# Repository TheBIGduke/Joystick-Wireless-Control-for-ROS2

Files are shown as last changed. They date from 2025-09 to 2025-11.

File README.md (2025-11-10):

# ESP32 Joystick Controller for ROS2






Control your ROS2 robot wirelessly using an ESP32 and analog joystick. Features real-time Socket.IO communication, variable speed control, and RGB LED status indicators.

## Features

- **Real-time wireless control** with analog joystick
- **Variable speed control** (half/full speed based on joystick position)
- **Seamless ROS2 integration** via delivery_bridge
- **RGB LED status indicators** for system feedback
- **Automatic reconnection** with robust error handling
- **Low-latency Socket.IO** communication

## Table of Contents

- [Hardware Requirements](#hardware-requirements)
- [Software Requirements](#software-requirements)
- [Installation](#installation)
- [Configuration](#configuration)
- [Usage](#usage)
- [LED Status Reference](#led-status-reference)
- [Troubleshooting](#troubleshooting)
- [Project Structure](#project-structure)
- [API Reference](#api-reference)
- [Contributing](#contributing)

## Hardware Requirements

### Components
- ESP32 Development Board (DevKitC, NodeMCU-32S, or compatible)
- Analog Joystick Module (2-axis with VRX/VRY outputs)
- Common Anode RGB LED
- Pushbutton (Dead Man Switch)
- 3× 220Ω resistors (for RGB LED)
- Jumper wires
- USB cable (micro-USB or USB-C)

### Wiring Diagram

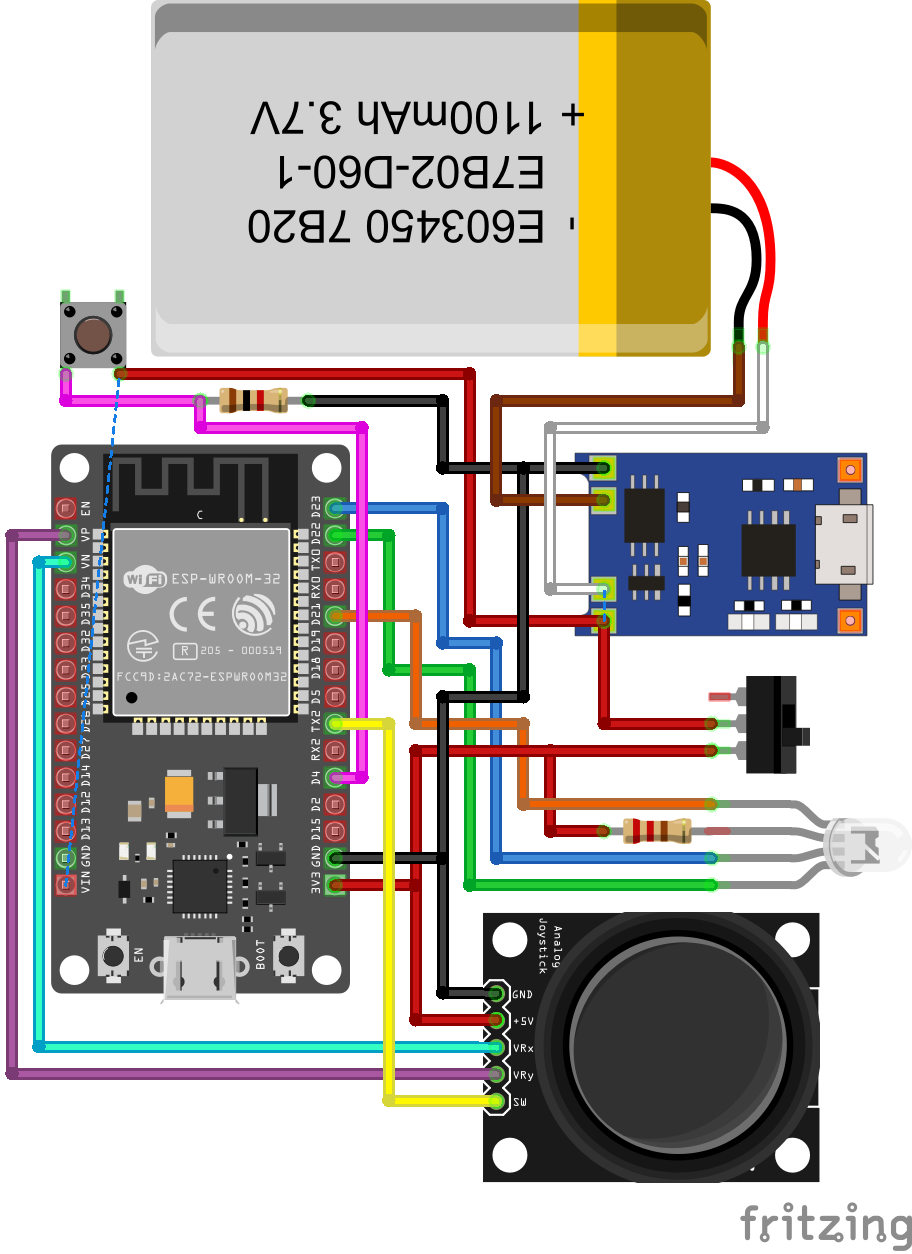
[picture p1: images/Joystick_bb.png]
ESP32 Wiring Diagram


#### Joystick Connections
```
Joystick → ESP32
VCC      → 3.3V
GND      → GND
VRX      → GPIO39 (ADC3)
VRY      → GPIO36 (ADC0)
```

#### Pushbutton (Dead Man Switch)
```
Pushbutton → ESP32
One side   → GPIO4
Other side → GND
```

#### RGB LED (Common Anode)
```
RGB LED        → ESP32
Red Cathode    → GPIO25 (+ 220Ω resistor)
Green Cathode  → GPIO26 (+ 220Ω resistor)
Blue Cathode   → GPIO27 (+ 220Ω resistor)
Common Anode   → 3.3V
```

## Software Requirements

- **Visual Studio Code** with PlatformIO IDE extension
- **ROS2** (Humble or newer)
- **Python 3.8+**
- **Git**

## Installation

### 1. Install Development Tools

#### Visual Studio Code + PlatformIO
1. Download and install [Visual Studio Code](https://code.visualstudio.com/)
2. Install PlatformIO IDE extension:
   - Open VS Code
   - Go to Extensions (`Ctrl+Shift+X`)
   - Search for "PlatformIO IDE"
   - Click "Install" and restart VS Code

### 2. Clone Repository

```bash
cd ~/colcon_ws/src
git clone https://github.com/TheBIGduke/Joystick-Wireless-Control-for-ROS2.git
cd Joystick-Wireless-Control-for-ROS2
```

### 3. Setup ROS2 Delivery Bridge

**Prerequisites:** ROS2 Humble or newer installed ([installation guide](https://docs.ros.org/en/humble/Installation.html))

```bash
# Install Python dependencies
cd delivery_bridge
pip install -r requirements.txt

# Build the ROS2 package
cd ~/colcon_ws
colcon build --packages-select delivery_bridge --symlink-install
source install/setup.bash

# Test the delivery bridge
ros2 run delivery_bridge server_node
```

**Expected output:**
```
[INFO] [server_node]: Starting node BaseNode ...
[INFO] [server_node]: Database created successfully.
INFO: Uvicorn running on http://0.0.0.0:9009
INFO: connection open
```

Verify at `http://localhost:9009/docs`

### 4. Setup ESP32 Project

```bash
cd ~/colcon_ws/src/Joystick-Wireless-Control-for-ROS2/Joystick_SocketIO_ESP32
code .
```

PlatformIO will automatically detect and initialize the project.

## Configuration

### Step 1: Find Server IP Address

Find the IP address of the computer running the delivery bridge:

**Linux:**
```bash
hostname -I
# or
ip addr show
```

### Step 2: Configure ESP32 Settings

Edit `Joystick_SocketIO_ESP32/src/main.cpp`:

```cpp
// ============ REQUIRED CONFIGURATION ============

// WiFi credentials
const char* ssid = "YOUR_WIFI_NAME";
const char* password = "YOUR_WIFI_PASSWORD";

// Socket.IO server (delivery bridge)
const char* socketio_host = "192.168.0.103";  // Replace with your server IP
const int socketio_port = 9009;

// ============ OPTIONAL TUNING ============

// Joystick calibration (adjust based on your joystick)
#define CENTER_X 1945
#define CENTER_Y 2005
#define DEADZONE 4

// Speed settings
const float LINEAR_SPEED_FULL = 0.4;   // m/s
const float LINEAR_SPEED_HALF = 0.2;   // m/s
const float ANGULAR_SPEED_FULL = 0.6;  // rad/s
const float ANGULAR_SPEED_HALF = 0.3;  // rad/s
const int SPEED_THRESHOLD = 250;       // Threshold for half vs full speed
```

### Step 3: Calibrate Joystick (Optional)

To get accurate center values:

1. Upload the default code to ESP32
2. Open Serial Monitor (9600 baud)
3. Observe joystick readings at rest position
4. Note the X and Y values (e.g., `x = 1945, y = 2005`)
5. Update `CENTER_X` and `CENTER_Y` in the code
6. Re-upload to ESP32

## Usage

### LED indicators (startup sequence)
Follow the LED colors during startup — do not move the joystick while calibration is in progress.

- 🟠 Orange (blinking) — Calibrating joystick. Do NOT move the joystick until the LED turns solid orange.
- 🟠 Orange (solid)  — Calibration complete; startup continues.
- 🔵 Blue (blinking) — Connecting to WiFi.
- 🔵 Blue (solid)    — WiFi connected.
- 🟡 Yellow (blinking) — Connecting to Socket.IO (delivery_bridge).
- 🟡 Yellow (solid)    — Socket.IO connected.
- 🟢 Green (solid)   — System ready. You may control the robot.

To move the robot: press and hold the deadman switch while operating the joystick.
To stop the robot: release the joystick to center OR (in emergencies) release the deadman switch immediately.

### 1. Start the Delivery Bridge

```bash
cd ~/colcon_ws
source /opt/ros/humble/setup.bash
source install/setup.bash
ros2 run delivery_bridge server_node
```

### 2. Upload Code to ESP32

**Using VS Code:**
1. Connect ESP32 via USB
2. Click PlatformIO icon in sidebar
3. Project Tasks → esp32doit-devkit-v1 → General → Upload

**Using CLI:**
```bash
cd Joystick_SocketIO_ESP32
pio run -t upload
```

### 3. Monitor Serial Output

```bash
pio device monitor -b 9600
```

**Expected output:**
```
Connecting to WiFi...
Connected to WiFi
IP address: 192.168.0.101
[IOc] Connected to url: /socket.io/?EIO=4
=== Joystick Wireless Control for ROS2 Started ===
Joystick - x = 0, y = 0
Movement: STOPPED | linear_x=0.00, angular_z=0.00
```

### 4. Verify ROS2 Communication

```bash
# Check cmd_vel topic
ros2 topic echo /cmd_vel
```

**Expected output when moving joystick:**
```
linear:
  x: 0.2
  y: 0.0
  z: 0.0
angular:
  x: 0.0
  y: 0.0
  z: -0.3
```

## LED Status Reference

| Color | Pattern | Status |
|---|---|---|
| 🔵 Blue | Fast blink | Connecting to WiFi |
| 🔵 Blue | Solid | WiFi connected |
| 🟡 Yellow | Fast blink | Connecting to Socket.IO |
| 🟡 Yellow | Solid | Socket.IO connected |
| 🟢 Green | Solid | System ready |
| 🟣 Magenta | Slow pulse | Dead man switch (no input) |
| 🟣 Magenta | Rapid pulse | Dead man switch (with input) |
| 🟠 Orange | Fast blink | Calibrating |
| 🔴 Red | Triple blink | Error |

## Troubleshooting

### WiFi Connection Issues

**Problem:** ESP32 won't connect to WiFi

**Solutions:**
- Verify WiFi credentials in `main.cpp`
- Ensure network is 2.4GHz (ESP32 doesn't support 5GHz)
- Check ESP32 is within router range
- Try a different WiFi network

### Socket.IO Connection Failed

**Problem:** WiFi connected but Socket.IO fails

**Solutions:**
- Verify delivery bridge is running: `ros2 run delivery_bridge server_node`
- Check server IP address in ESP32 code matches your computer
- Ensure both devices are on the same network
- Test server: `telnet YOUR_IP 9009`

### Joystick Not Responding

**Problem:** Robot doesn't move when joystick is moved

**Solutions:**
- **Check wiring:** VRX→GPIO39, VRY→GPIO36, VCC→3.3V, GND→GND
- **Verify power:** Joystick receives 3.3V
- **Calibrate:** Update `CENTER_X` and `CENTER_Y` values
- **Check serial:** Monitor joystick readings
- **Adjust deadzone:** If too sensitive, increase `DEADZONE` value

### Wrong Movement Direction

**Problem:** Robot moves in unexpected directions

**Solutions:**
- Swap VRX/VRY pin connections
- Or modify code to invert axes:
```cpp
// In readJoystick() function:
valueX = -analogRead(VRY_PIN);  // Add minus sign
```

### Robot Doesn't Move

**Problem:** ESP32 connected but robot unresponsive

**Solutions:**
- Check ROS2 topics: `ros2 topic list`
- Monitor cmd_vel: `ros2 topic echo /cmd_vel`
- Verify delivery bridge logs show received events
- Check robot is in correct operational mode

### Serial Monitor Shows Nothing

**Problem:** No output in serial monitor

**Solutions:**
- Verify baud rate is 9600
- Check USB cable connection
- Try different USB port
- Press ESP32 reset button
- Confirm correct COM port

## Project Structure

```
Joystick-Wireless-Control-for-ROS2/
├── Joystick_SocketIO_ESP32/
│   ├── src/
│   │   └── main.cpp              # ESP32 joystick controller
│   ├── platformio.ini            # PlatformIO configuration
│   └── .vscode/
├── delivery_bridge/
│   ├── delivery_bridge/
│   │   ├── base_node.py          # ROS2 base node
│   │   ├── server_node.py        # Socket.IO server
│   │   └── modules/              # ROS2 functionality
│   ├── package.xml
│   ├── setup.py
│   └── requirements.txt
└── README.md
```

## API Reference

### cmd_vel Message Format

ESP32 sends velocity commands to ROS2:

```json
[
  "cmd_vel",
  {
    "linear_x": 0.2,    // Forward/backward (m/s)
    "angular_z": 0.1    // Rotation (rad/s)
  }
]
```

**Speed Control:**
- **Half Speed:** `|joystick_value| ≤ SPEED_THRESHOLD`
- **Full Speed:** `|joystick_value| > SPEED_THRESHOLD`
- **Stopped:** Joystick in deadzone

### Delivery Bridge Endpoints

**HTTP REST API:**
```
POST /ros/functionality_mode/     # Set robot mode
GET  /waypoints/waypoint          # Get waypoints
POST /navigation/set_goal/{id}    # Navigate to waypoint
POST /navigation/set_wp/pause     # Pause navigation
POST /navigation/set_wp/resume    # Resume navigation
POST /navigation/set_wp/stop      # Stop navigation
```

**Socket.IO Events (Server → ESP32):**
```json
["battery", {"voltage": 12.5, "percentage": 85.2}]
["robot_pose", {"position_x": 1.2, "position_y": 3.4}]
["on_status_change", {"general": {"ready": true}}]
```

Full API documentation: `http://YOUR_SERVER_IP:9009/docs`

## Contributing

Contributions welcome! 

1. Fork the repository
2. Create a feature branch
3. Make your changes
4. Test thoroughly
5. Submit a pull request

## Acknowledgments

### Original Delivery Bridge
- **Author:** C. Mauricio Arteaga-Escamilla ([@cmauricioae8](https://github.com/cmauricioae8))
- **Repository:** [delivery_bridge](https://github.com/cmauricioae8/delivery_bridge)

### ESP32 Joystick Controller
- **Author:** Kaléin Tamaríz - TheBIGduke
- **Version:** 2.0.0

---

**Made with care for the ESP32 and ROS2 community**

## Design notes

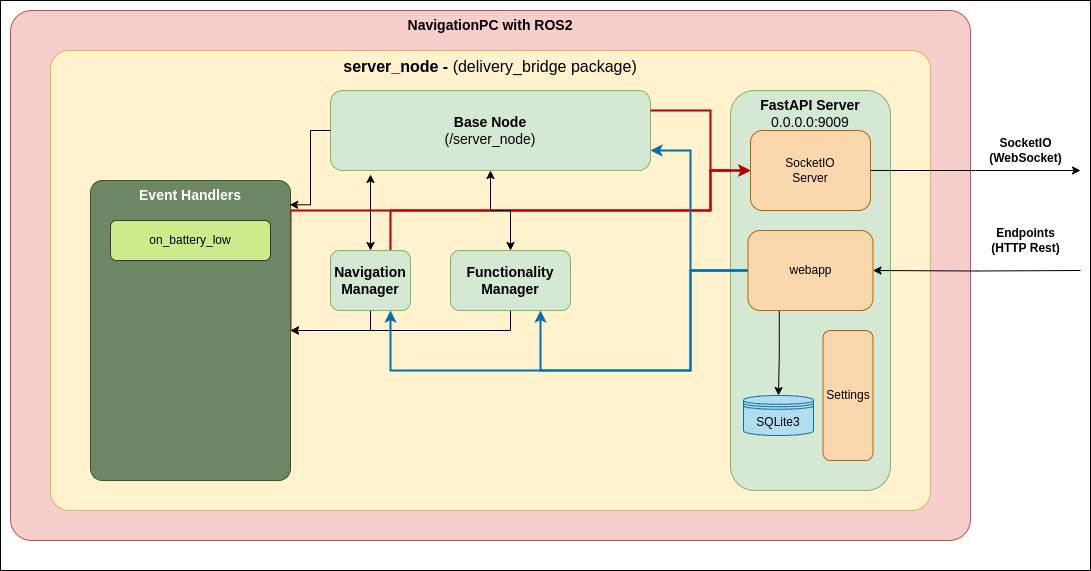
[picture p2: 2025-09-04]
delivery_bridge/docs/_static/general_diag.drawio.png

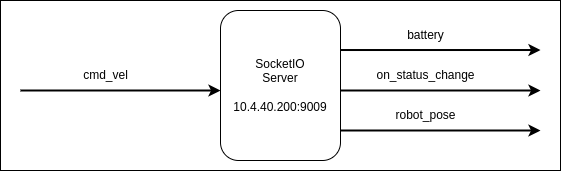
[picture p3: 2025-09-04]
delivery_bridge/docs/_static/sio_events.drawio.png

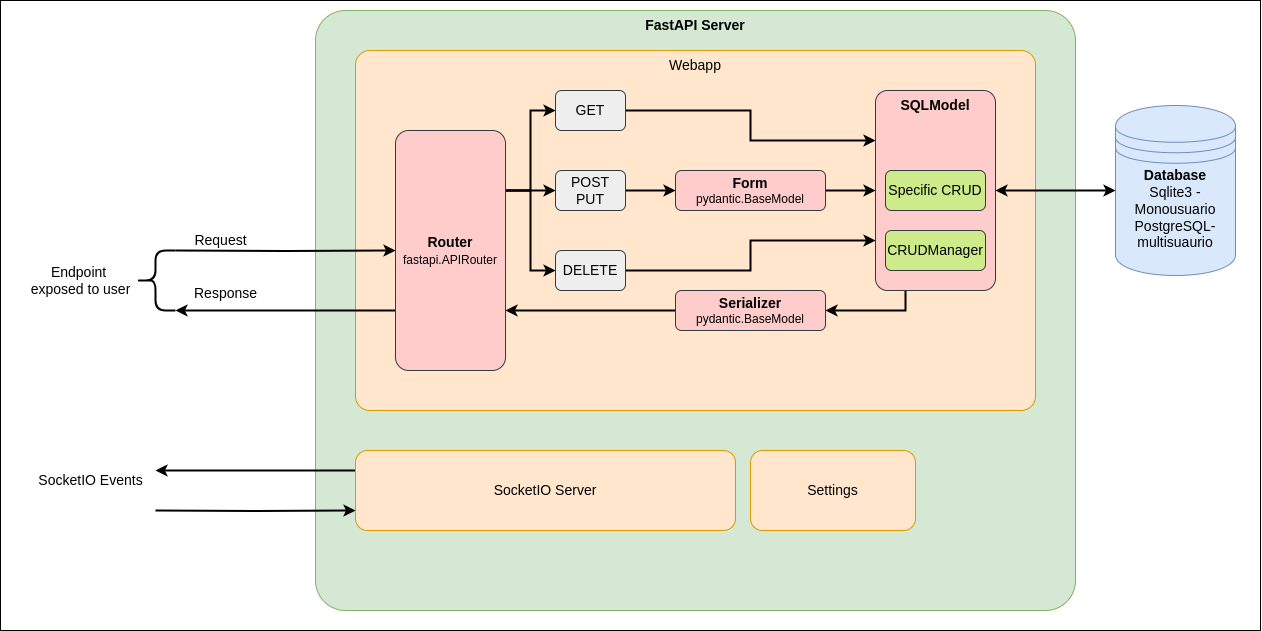
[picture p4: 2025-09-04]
delivery_bridge/docs/_static/fastapi_server.drawio.png

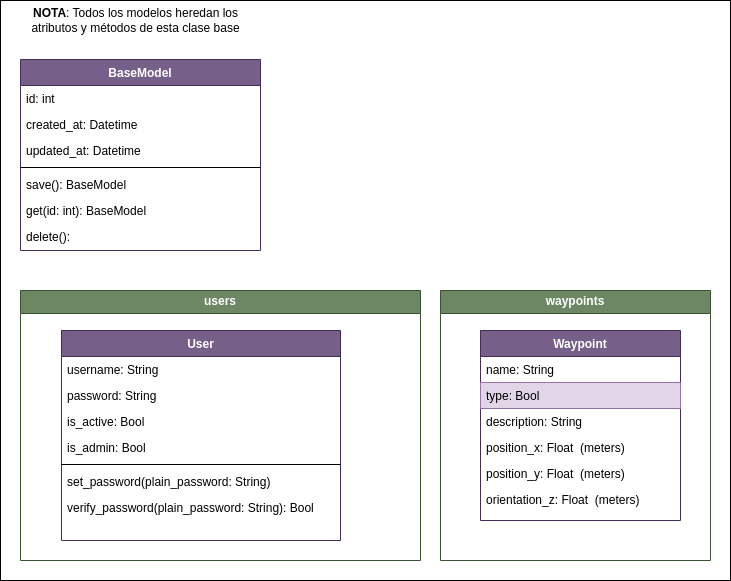
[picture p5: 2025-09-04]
delivery_bridge/docs/_static/models_tables.drawio.png

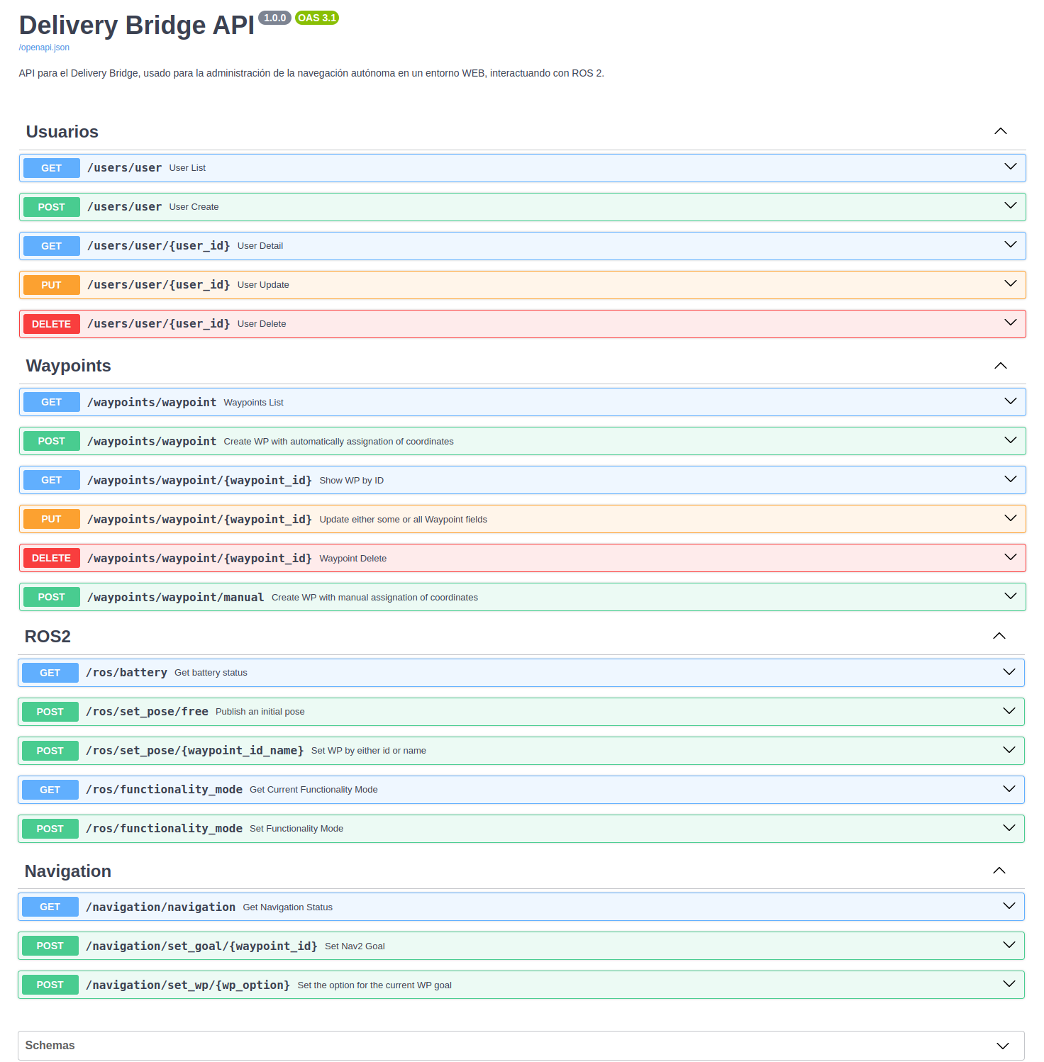
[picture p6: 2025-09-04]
delivery_bridge/docs/swagger.png

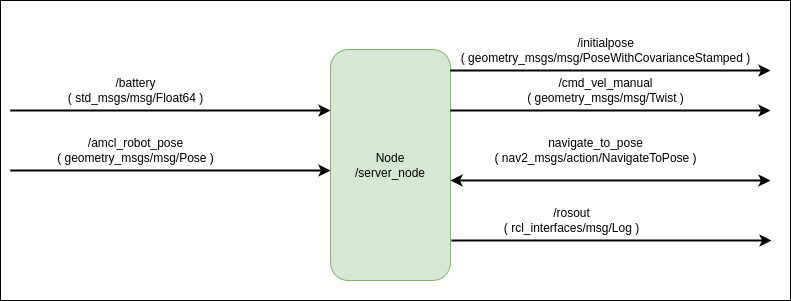
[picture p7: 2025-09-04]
delivery_bridge/docs/_static/ros_node.drawio.png

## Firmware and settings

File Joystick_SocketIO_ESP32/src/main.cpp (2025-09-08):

/**
 * Joystick Wireless Control for ROS2
 * 
 * An implementation of a Joystick to control a robot wirelessly using an ESP32.
 * This system uses Socket.IO communication to send real-time joystick commands
 * to ROS2 robots through the delivery_bridge package.
 * 
 * Features:
 * - Analog joystick input reading with calibration
 * - Wireless control via WiFi and Socket.IO
 * - Variable speed control (half/full speed based on joystick position)
 * - Real-time cmd_vel command transmission to ROS2
 * - Automatic reconnection and error handling
 * - Deadzone filtering for precise control
 * - RGB LED status indicator
 * - Dead man switch safety feature
 * 
 * @author Kaléin Tamaríz - TheBIGduke
 * @version 2.0.0
 */

// ============= LIBRARY INCLUDES =============
#include <Arduino.h>            // Arduino core functions for PlatformIO
#include <WiFi.h>               // ESP32 WiFi functionality
#include <SocketIOclient.h>     // Socket.IO client library


// ============= CONFIGURATION SECTION =============
// Update these values for your specific setup

// --- WiFi Configuration ---
const char* ssid = "ESP32";               // WiFi network name
const char* password = "12345678";        // WiFi password

// Socket.IO server configuration
const char* socketio_host = "192.168.0.103";  // IP address of the ROS2 machine
const int socketio_port = 9009;               // Socket.IO server port

// --- Joystick Hardware Configuration ---
#define VRX_PIN  39              // ESP32 pin GPIO39 (ADC3) connected to VRX pin
#define VRY_PIN  36              // ESP32 pin GPIO36 (ADC0) connected to VRY pin

// Joystick calibration values (will be automatically calibrated on startup)
int CENTER_X_CALIBRATED = 2048;  // Default center for X axis
int CENTER_Y_CALIBRATED = 2048;  // Default center for Y axis
#define MAX_X    4095             // Maximum value for X axis
#define MAX_Y    4095             // Maximum value for Y axis

// --- Safety Switch Configuration ---
#define DEADMAN_BUTTON_PIN 4     // ESP32 pin GPIO4 connected to pushbutton

// --- LED Indicator Configuration ---
// RGB LED pins
#define LED_RED_PIN 21
#define LED_GREEN_PIN 22
#define LED_BLUE_PIN 23

// PWM channels (ESP32 specific)
#define RED_CHANNEL 0
#define GREEN_CHANNEL 1
#define BLUE_CHANNEL 2

// PWM settings
#define PWM_FREQ 5000            // PWM frequency
#define PWM_RESOLUTION 8         // 8-bit resolution (0-255)

// --- Movement Parameters ---
const float LINEAR_SPEED_FULL = 0.4;   // Full linear velocity (m/s)
const float LINEAR_SPEED_HALF = 0.2;   // Half linear velocity (m/s)
const float ANGULAR_SPEED_FULL = 0.6;  // Full angular velocity (rad/s)
const float ANGULAR_SPEED_HALF = 0.3;  // Half angular velocity (rad/s)

// Speed thresholds (based on joystick range)
const int SPEED_THRESHOLD = 250;       // Threshold for half vs full speed

// Command velocity send interval
const unsigned long CMD_VEL_INTERVAL = 100; // ms between cmd_vel commands

// Calibration parameters
const int CALIBRATION_SAMPLES = 1000;  // Number of samples for calibration
const int CALIBRATION_DELAY = 2;       // Delay between samples (ms)


// ============= ENUMERATIONS =============
// LED states for system status indication
enum LEDstate {
  LED_CALIBRATING,           // Calibration in progress
  LED_CALIBRATION_DONE,      // Calibration completed
  LED_WIFI_CONNECTING,       // WiFi connection in progress
  LED_WIFI_CONNECTED,        // WiFi connected successfully
  LED_SOCKETIO_CONNECTING,   // Socket.IO connection in progress
  LED_SOCKETIO_CONNECTED,    // Socket.IO connected successfully
  LED_SOCKETIO_ERROR,        // Socket.IO connection failed
  LED_SYSTEM_ONLINE,         // System fully operational
  LED_DEADMAN_NO_INPUT,      // Dead man active but no joystick input
  LED_DEADMAN_WITH_INPUT     // Dead man active with joystick input
};

// System states
enum SystemState {
  STATE_CALIBRATING,
  STATE_CONNECTING_WIFI,
  STATE_CONNECTING_SOCKETIO,
  STATE_READY,
  STATE_ERROR_DISPLAY  // Added state for showing error before reconnecting
};

// Solid color states for LED
#define COLOR_OFF 0
#define COLOR_RED 1
#define COLOR_GREEN 2
#define COLOR_BLUE 3
#define COLOR_MAGENTA 4
#define COLOR_ORANGE 5
#define COLOR_YELLOW 6

// Blinking modes for status indication
#define BLINK_FAST 0
#define BLINK_MEDIUM 1
#define BLINK_HOLD 2
#define BLINK_DOUBLE 3        // off blink blink off blink blink off
#define BLINK_TRIPLE 4        // off blink blink blink off blink blink blink off
#define BLINK_HEARTBEAT 5
#define BLINK_RAPID_PULSE 6


// ============= GLOBAL VARIABLES =============
SocketIOclient socketIO;              // Socket.IO client instance

// Joystick and control variables
int valueX = 0;                       // Current X-axis value (centered, mapped)
int valueY = 0;                       // Current Y-axis value (centered, mapped)
unsigned long lastCmdVel = 0;         // Last time cmd_vel was sent (for rate limiting)

// Dead man switch variables
bool deadmanPressed = false;          // Current dead man switch state
bool lastDeadmanState = false;        // Previous dead man switch state (for edge detection)

// LED indicator variables
unsigned long blinkTimer = 0;         // Timer for LED blinking patterns
bool blinkState = false;              // Current LED blink state (on/off)
int blinkCycle = 0;                   // Current blink cycle (for pattern arrays)

// Error state handling
unsigned long errorStartTime = 0;     // When the error state started (for error display timing)
const unsigned long ERROR_DISPLAY_TIME = 3000; // 3 seconds to show error

// Calibration variables
long sumX = 0, sumY = 0;              // Sum of calibration samples (for averaging)
int calibrationSamplesTaken = 0;      // Number of calibration samples taken
unsigned long calibrationStartTime = 0; // When calibration started
SystemState systemState = STATE_CALIBRATING; // Current system state
LEDstate currentLEDState = LED_CALIBRATING; // Current LED state
unsigned long socketRetryTime = 0;    // Time when socket retry started
bool socketConnectionFailed = false;  // Flag for socket connection failure
const unsigned long SOCKET_RETRY_DELAY = 5000; // 5 seconds before retry


// ============= FUNCTION PROTOTYPES =============
// LED control functions
void setSolidColor(int color);
void setBlinkingMode(int blinkMode, int color);
void setLEDState(LEDstate state);
void updateLED();

// Joystick functions
void calibrateJoystick();
void readJoystick();
float calculateLinearSpeed(int joystickValue);
float calculateAngularSpeed(int joystickValue);

// Socket.IO functions
void socketIOEvent(socketIOmessageType_t type, uint8_t * payload, size_t length);

// Movement functions
String getMovementDescription(float linear_x, float angular_z);
void sendCmdVel(float linear_x, float angular_z);
void processJoystickInput();

// Utility functions
bool readDeadmanSwitch();
void handleCalibration();
void handleWiFiConnection();
void handleSocketIOConnection();


// ============= SETUP FUNCTION =============
void setup() {
  // Initialize serial communication
  Serial.begin(9600);
  Serial.setDebugOutput(true);
  Serial.println("\n=== Joystick Wireless Control for ROS2 ===");

  // Configure PWM channels for RGB LED
  ledcSetup(RED_CHANNEL, PWM_FREQ, PWM_RESOLUTION);
  ledcSetup(GREEN_CHANNEL, PWM_FREQ, PWM_RESOLUTION);
  ledcSetup(BLUE_CHANNEL, PWM_FREQ, PWM_RESOLUTION);
  
  // Attach pins to PWM channels
  ledcAttachPin(LED_RED_PIN, RED_CHANNEL);
  ledcAttachPin(LED_GREEN_PIN, GREEN_CHANNEL);
  ledcAttachPin(LED_BLUE_PIN, BLUE_CHANNEL);
  
  // Start with all LEDs off
  setSolidColor(COLOR_OFF);

  // Configure ADC for joystick
  analogSetAttenuation(ADC_11db);  // Set ADC attenuation to 11 dB (up to ~3.3V input)
  
  // Configure dead man switch button (active LOW)
  pinMode(DEADMAN_BUTTON_PIN, INPUT_PULLUP);
  Serial.println("Dead man switch configured on GPIO4 (active LOW)");
  
  // Start calibration process
  setLEDState(LED_CALIBRATING);
  calibrationStartTime = millis();
  Serial.println("=== JOYSTICK CALIBRATION ===");
  Serial.println("Please center your joystick and keep it still...");
  Serial.println("Calibrating in 5 seconds...");
}


// ============= MAIN LOOP =============
void loop() {
  // Update LED state (visual feedback)
  updateLED();
  
  // Handle different system states
  switch(systemState) {
    case STATE_ERROR_DISPLAY:
      // Show error for 3 seconds before attempting to reconnect
      if (millis() - errorStartTime >= ERROR_DISPLAY_TIME) {
        systemState = STATE_CONNECTING_SOCKETIO;
      }
      break;
      
    case STATE_CALIBRATING:
      handleCalibration(); // Non-blocking calibration
      break;
      
    case STATE_CONNECTING_WIFI:
      handleWiFiConnection(); // Non-blocking WiFi connection
      break;
      
    case STATE_CONNECTING_SOCKETIO:
      handleSocketIOConnection(); // Non-blocking Socket.IO connection
      break;
      
    case STATE_READY:
      socketIO.loop(); // Handle Socket.IO events
      readJoystick();  // Read joystick input
      // Send cmd_vel commands at regular intervals
      if (millis() - lastCmdVel >= CMD_VEL_INTERVAL) {
        lastCmdVel = millis();
        processJoystickInput();
      }
      break;
  }
  
  delay(10);  // Small delay to maintain stability
}


// ============= CALIBRATION FUNCTIONS =============

/**
 * Handles the calibration process in a non-blocking way
 */
void handleCalibration() {
  static int countdown = 5; // Countdown before calibration starts
  static unsigned long lastCountdownTime = 0;
  
  // Countdown phase
  if (countdown > 0) {
    if (millis() - lastCountdownTime >= 1000) {
      lastCountdownTime = millis();
      Serial.println(String(countdown) + "...");
      countdown--;
      
      if (countdown == 0) {
        Serial.println("Calibrating... DO NOT MOVE THE JOYSTICK!");
      }
    }
    return;
  }
  
  // Calibration sampling phase
  if (calibrationSamplesTaken < CALIBRATION_SAMPLES) {
    if (millis() - calibrationStartTime >= CALIBRATION_DELAY) {
      calibrationStartTime = millis();
      
      sumX += analogRead(VRY_PIN);  // Note: X and Y are swapped in reading
      sumY += analogRead(VRX_PIN);  // to match physical orientation
      calibrationSamplesTaken++;
      
      if (calibrationSamplesTaken % 100 == 0) {
        Serial.print(".");
      }
    }
    return;
  }
  
  // Calibration complete
  Serial.println();
  
  // Calculate average center values
  CENTER_X_CALIBRATED = sumX / CALIBRATION_SAMPLES;
  CENTER_Y_CALIBRATED = sumY / CALIBRATION_SAMPLES;
  
  Serial.println("Calibration complete!");
  Serial.println("CENTER_X: " + String(CENTER_X_CALIBRATED));
  Serial.println("CENTER_Y: " + String(CENTER_Y_CALIBRATED));
  
  // Test the calibration
  Serial.println("\nTesting calibration (keep joystick centered):");
  for(int i = 0; i < 5; i++) {
    int testX = analogRead(VRY_PIN);
    int testY = analogRead(VRX_PIN);
    int mappedX = (testX - CENTER_X_CALIBRATED) * 1000 / MAX_X;
    int mappedY = (testY - CENTER_Y_CALIBRATED) * 1000 / MAX_Y;
    Serial.println("Raw(" + String(testX) + "," + String(testY) + 
                   ") -> Mapped(" + String(mappedX) + "," + String(mappedY) + ")");
    delay(200);
  }
  
  Serial.println("=== CALIBRATION COMPLETE ===\n");
  setLEDState(LED_CALIBRATION_DONE);
  delay(1000);
  
  // Move to next state
  systemState = STATE_CONNECTING_WIFI;
  setLEDState(LED_WIFI_CONNECTING);
  WiFi.begin(ssid, password);
}


// ============= CONNECTION HANDLING FUNCTIONS =============

/**
 * Handles WiFi connection process
 */
void handleWiFiConnection() {
  if (WiFi.status() == WL_CONNECTED) {
    Serial.println("\nConnected to WiFi");
    Serial.print("IP address: ");
    Serial.println(WiFi.localIP());
    setLEDState(LED_WIFI_CONNECTED);
    delay(3000);
    
    // Move to next state
    systemState = STATE_CONNECTING_SOCKETIO;
    setLEDState(LED_SOCKETIO_CONNECTING);
    socketIO.begin(socketio_host, socketio_port, "/socket.io/?EIO=4");
    socketIO.onEvent(socketIOEvent);
    return;
  }
  
  // Show connection progress
  static unsigned long lastPrintTime = 0;
  if (millis() - lastPrintTime >= 500) {
    lastPrintTime = millis();
    Serial.print(".");
  }
}

/**
 * Handles Socket.IO connection process
 */
void handleSocketIOConnection() {
  static unsigned long connectionStartTime = millis();
  const unsigned long CONNECTION_TIMEOUT = 10000; // 10 seconds timeout
  static bool socketInitialized = false;

  // Initialize socket if not already done
  if (!socketInitialized) {
    Serial.println("Initializing Socket.IO connection...");
    setLEDState(LED_SOCKETIO_CONNECTING);
    socketIO.begin(socketio_host, socketio_port, "/socket.io/?EIO=4");
    socketIO.onEvent(socketIOEvent);
    socketInitialized = true;
    connectionStartTime = millis();
    return;
  }

  // Handle connection timeout
  if (millis() - connectionStartTime > CONNECTION_TIMEOUT && !socketConnectionFailed) {
    Serial.println("Socket.IO connection timeout!");
    setLEDState(LED_SOCKETIO_ERROR);
    errorStartTime = millis();  // Start the error display timer
    socketConnectionFailed = true;
    socketRetryTime = millis();
    socketInitialized = false; // Reset for next attempt
    systemState = STATE_ERROR_DISPLAY;  // Transition to error display state
    return;
  }
  
  // Handle retry after timeout
  if (socketConnectionFailed) {
    if (millis() - socketRetryTime >= SOCKET_RETRY_DELAY) {
      Serial.println("Retrying Socket.IO connection...");
      socketConnectionFailed = false;
      socketInitialized = false; // This will trigger re-initialization in the next loop
    }
    return;
  }
  
  // Process socket events in the main loop
  socketIO.loop();
}


// ============= JOYSTICK FUNCTIONS =============

/**
 * Reads raw values from joystick and converts to centered coordinates
 * Applies deadzone filtering to prevent drift
 */
void readJoystick() {
  // Read X and Y analog values (note: pins are swapped to match orientation)
  valueX = analogRead(VRY_PIN);
  valueY = analogRead(VRX_PIN);

  // Map values so center is 0, left/up is negative, right/down is positive
  valueX = (valueX - CENTER_X_CALIBRATED) * 1000 / MAX_X;
  valueY = (valueY - CENTER_Y_CALIBRATED) * 1000 / MAX_Y;

  // Apply deadzone to prevent drift around center
  const int deadzone = 10;
  if (abs(valueX) < deadzone) valueX = 0;
  if (abs(valueY) < deadzone) valueY = 0;
}

/**
 * Calculates linear speed based on joystick position
 * @param joystickValue The joystick position value (-1000 to 1000)
 * @return Linear speed value with appropriate sign
 */
float calculateLinearSpeed(int joystickValue) {
  int absValue = abs(joystickValue);
  
  if (absValue == 0) {
    return 0.0;  // No movement
  }
  else if (absValue <= SPEED_THRESHOLD) {
    // Half speed for middle range
    return (joystickValue > 0) ? LINEAR_SPEED_HALF : -LINEAR_SPEED_HALF;
  }
  else {
    // Full speed for extreme positions
    return (joystickValue > 0) ? LINEAR_SPEED_FULL : -LINEAR_SPEED_FULL;
  }
}

/**
 * Calculates angular speed based on joystick position
 * @param joystickValue The joystick position value (-1000 to 1000)
 * @return Angular speed value with appropriate sign
 */
float calculateAngularSpeed(int joystickValue) {
  int absValue = abs(joystickValue);
  
  if (absValue == 0) {
    return 0.0;  // No rotation
  }
  else if (absValue <= SPEED_THRESHOLD) {
    // Half speed for middle range
    return (joystickValue > 0) ? ANGULAR_SPEED_HALF : -ANGULAR_SPEED_HALF;
  }
  else {
    // Full speed for extreme positions
    return (joystickValue > 0) ? ANGULAR_SPEED_FULL : -ANGULAR_SPEED_FULL;
  }
}


// ============= MOVEMENT FUNCTIONS =============

/**
 * Processes joystick input and sends appropriate movement commands
 * Only sends commands when dead man switch is pressed
 */
void processJoystickInput() {
  // Read dead man switch state
  deadmanPressed = readDeadmanSwitch();
  
  // Provide feedback when button state changes
  if (deadmanPressed != lastDeadmanState) {
    if (deadmanPressed) {
      Serial.println("*** DEAD MAN SWITCH: ACTIVE - Robot control ENABLED ***");
      setLEDState(LED_DEADMAN_NO_INPUT);
    } else {
      Serial.println("*** DEAD MAN SWITCH: RELEASED - Robot control DISABLED ***");
      setLEDState(LED_SYSTEM_ONLINE);
      // Send stop command when button is released
      sendCmdVel(0.0, 0.0);
    }
    lastDeadmanState = deadmanPressed;
  }
  
  float linear_x = 0.0;
  float angular_z = 0.0;
  
  // Only process joystick input if dead man switch is pressed
  if (deadmanPressed) {
    // Update LED state based on whether there's input
    if (valueX != 0 || valueY != 0) {
      setLEDState(LED_DEADMAN_WITH_INPUT);
    } else {
      setLEDState(LED_DEADMAN_NO_INPUT);
    }
    
    // Calculate speeds based on joystick positions
    // Forward/Backward control (Y-axis)
    if (valueY != 0) {
      linear_x = calculateLinearSpeed(valueY);
    }
    
    // Left/Right rotation control (X-axis)
    if (valueX != 0) {
      angular_z = -calculateAngularSpeed(valueX); // Negative for correct rotation direction
    }
  }
  
  // Send movement command
  sendCmdVel(linear_x, angular_z);
}

/**
 * Sends movement command to ROS2 via Socket.IO
 * @param linear_x Linear velocity (m/s)
 * @param angular_z Angular velocity (rad/s)
 */
void sendCmdVel(float linear_x, float angular_z) {
  // Create cmd_vel JSON payload
  String payload = "[\"cmd_vel\",{\"linear_x\":" + String(linear_x) + 
                   ",\"angular_z\":" + String(angular_z) + "}]";
  
  // Send cmd_vel event to ROS2 robot
  socketIO.sendEVENT(payload);
  
  // Print movement description for debugging
  Serial.println("Movement: " + getMovementDescription(linear_x, angular_z) + 
                 " | linear_x=" + String(linear_x) + ", angular_z=" + String(angular_z));
}

/**
 * Returns a descriptive string for the current movement
 * @param linear_x Linear velocity value
 * @param angular_z Angular velocity value
 * @return String describing the movement
 */
String getMovementDescription(float linear_x, float angular_z) {
  if (linear_x > 0 && angular_z == 0) return "FORWARD";
  else if (linear_x < 0 && angular_z == 0) return "BACKWARD";
  else if (linear_x == 0 && angular_z > 0) return "ROTATE_LEFT";
  else if (linear_x == 0 && angular_z < 0) return "ROTATE_RIGHT";
  else if (linear_x == 0 && angular_z == 0) return "STOPPED";
  else return "COMBINED_MOVEMENT";
}


// ============= SOCKET.IO FUNCTIONS =============

/**
 * Handles Socket.IO events
 * @param type Type of Socket.IO message
 * @param payload Message payload
 * @param length Payload length
 */
void socketIOEvent(socketIOmessageType_t type, uint8_t * payload, size_t length) {
  switch(type) {
    case sIOtype_DISCONNECT:
      Serial.printf("[IOc] Disconnected!\n");
      if (systemState == STATE_READY) {
        setLEDState(LED_SOCKETIO_ERROR);
        errorStartTime = millis();  // Start the error display timer
        systemState = STATE_ERROR_DISPLAY;  // New state to show error before reconnecting
      }
      break;
    case sIOtype_CONNECT:
      Serial.printf("[IOc] Connected to url: %s\n", payload);
      // Join default namespace
      socketIO.send(sIOtype_CONNECT, "/");
      
      // Transition to ready state and set system online LED
      systemState = STATE_READY;
      setLEDState(LED_SYSTEM_ONLINE);
      
      // Print control information
      Serial.println("=== Control Configuration ===");
      Serial.println("Joystick Controls with Variable Speed:");
      Serial.println("- Y-axis: Forward/Backward movement");
      Serial.println("- X-axis: Left/Right rotation");
      Serial.println("- Speed: Half speed for |value| <= " + String(SPEED_THRESHOLD) + 
                    ", Full speed for |value| > " + String(SPEED_THRESHOLD));
      Serial.println("- Linear speeds: Half=" + String(LINEAR_SPEED_HALF) + 
                    "m/s, Full=" + String(LINEAR_SPEED_FULL) + "m/s");
      Serial.println("- Angular speeds: Half=" + String(ANGULAR_SPEED_HALF) + 
                    "rad/s, Full=" + String(ANGULAR_SPEED_FULL) + "rad/s");
      Serial.println("\n=== SAFETY FEATURES ===");
      Serial.println("- Dead man switch: GPIO4 button must be pressed for robot control");
      Serial.println("- Robot will STOP immediately when button is released");
      Serial.println("\nReady for operation. HOLD THE DEAD MAN SWITCH to enable control.");
      break;
    case sIOtype_EVENT:
      Serial.printf("[IOc] get event: %s\n", payload);
      break;
    case sIOtype_ACK:
      Serial.printf("[IOc] get ack: %u\n", length);
      break;
    case sIOtype_ERROR:
      Serial.printf("[IOc] get error: %u\n", length);
      setLEDState(LED_SOCKETIO_ERROR);
      break;
    case sIOtype_BINARY_EVENT:
    case sIOtype_BINARY_ACK:
      // Not used in this implementation
      break;
  }
}


// ============= LED CONTROL FUNCTIONS =============
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

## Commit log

2025-09-04 Added Dead-man switch function and tunned the autocalibration
2025-09-05 Added RGB Led indicator logic
2025-09-05 Added the retry function to connect to SocketIO and fixed minor bugs
    [main.cpp]
2025-09-05 Fixed minor bugs with the LED indicator
    [main.cpp]
2025-09-24 Fritzing Circuit
    [Joystick.fzz]
2025-11-10 Updated the circuit
2025-11-10 Added the LED indicators to the README.md
2025-11-10 Updated Joystick.fzz file
    [Joystick.fzz]
